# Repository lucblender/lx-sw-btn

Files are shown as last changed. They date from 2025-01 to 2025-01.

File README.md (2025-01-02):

# lx-sw-btn

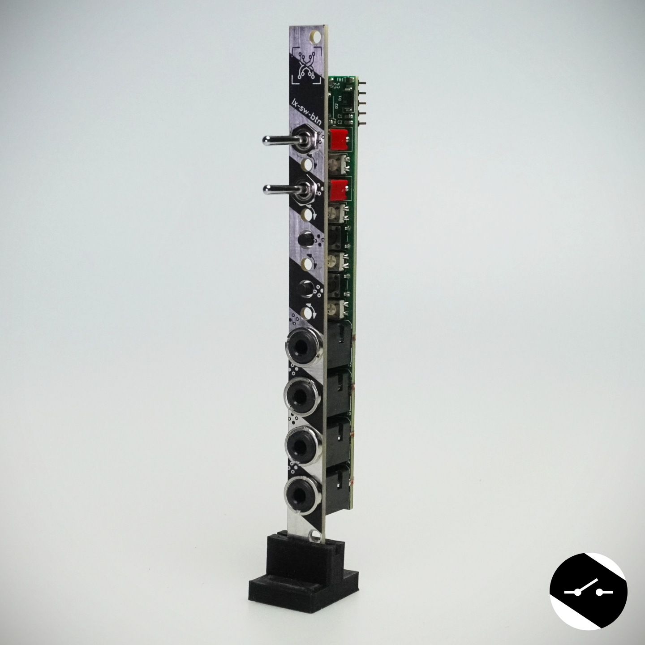
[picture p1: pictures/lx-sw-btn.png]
lx-sw-btn


This repository contains the KiCad project for the "lx-sw-btn": a 2HP eurorack module with 4 customizable switches enabled CV outputs!

With two buttons and two switches, the lx-sw-btn enables four CV "on-off" outputs. By default, the output is set to 0-5V, but each output can be fine-tuned through front-panel adjustment holes ranging from -10V to +10V. This will allow you to use the switches not only as triggers but also for precise CV control.

The module is extremely compact with only a single PCB featuring SMD components on both sides, ensuring no wasted space!

I used [PCBWay](pcbway.com) services were used for the PCB manufacturing, both pcb and front panel.

## Content

Under the [hardware](/hardware/) folder, you will find the KiCad project with the following files:

- [Project](/hardware/2hp-simple-switch-button/2hp-simple-switch-button.kicad_pro)
- [Schematic](/hardware/2hp-simple-switch-button/2hp-simple-switch-button.kicad_sch)
- [Main PCB](/hardware/2hp-simple-switch-button/2hp-simple-switch-button.kicad_pcb)
- [Front panel PCB](/hardware/2hp-simple-switch-button/2hp-simple-switch-button-front-panel.kicad_pcb)

## Circuit

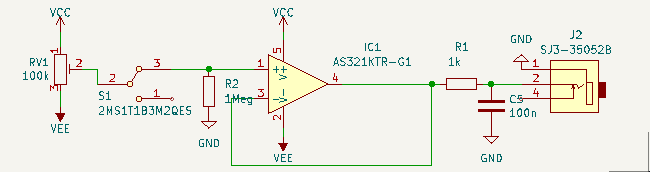
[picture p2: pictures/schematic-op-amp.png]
schematic-exerp


The circuit consist of 4 times the circuit below: an opamp as follower with a voltage devider between VCC and VEE as input through a potentiometer. The output is set to 1k impedance with a RC filter useful for debouncing the switches and buttons.

The module also have power supply invert polarity protection and input filtering.

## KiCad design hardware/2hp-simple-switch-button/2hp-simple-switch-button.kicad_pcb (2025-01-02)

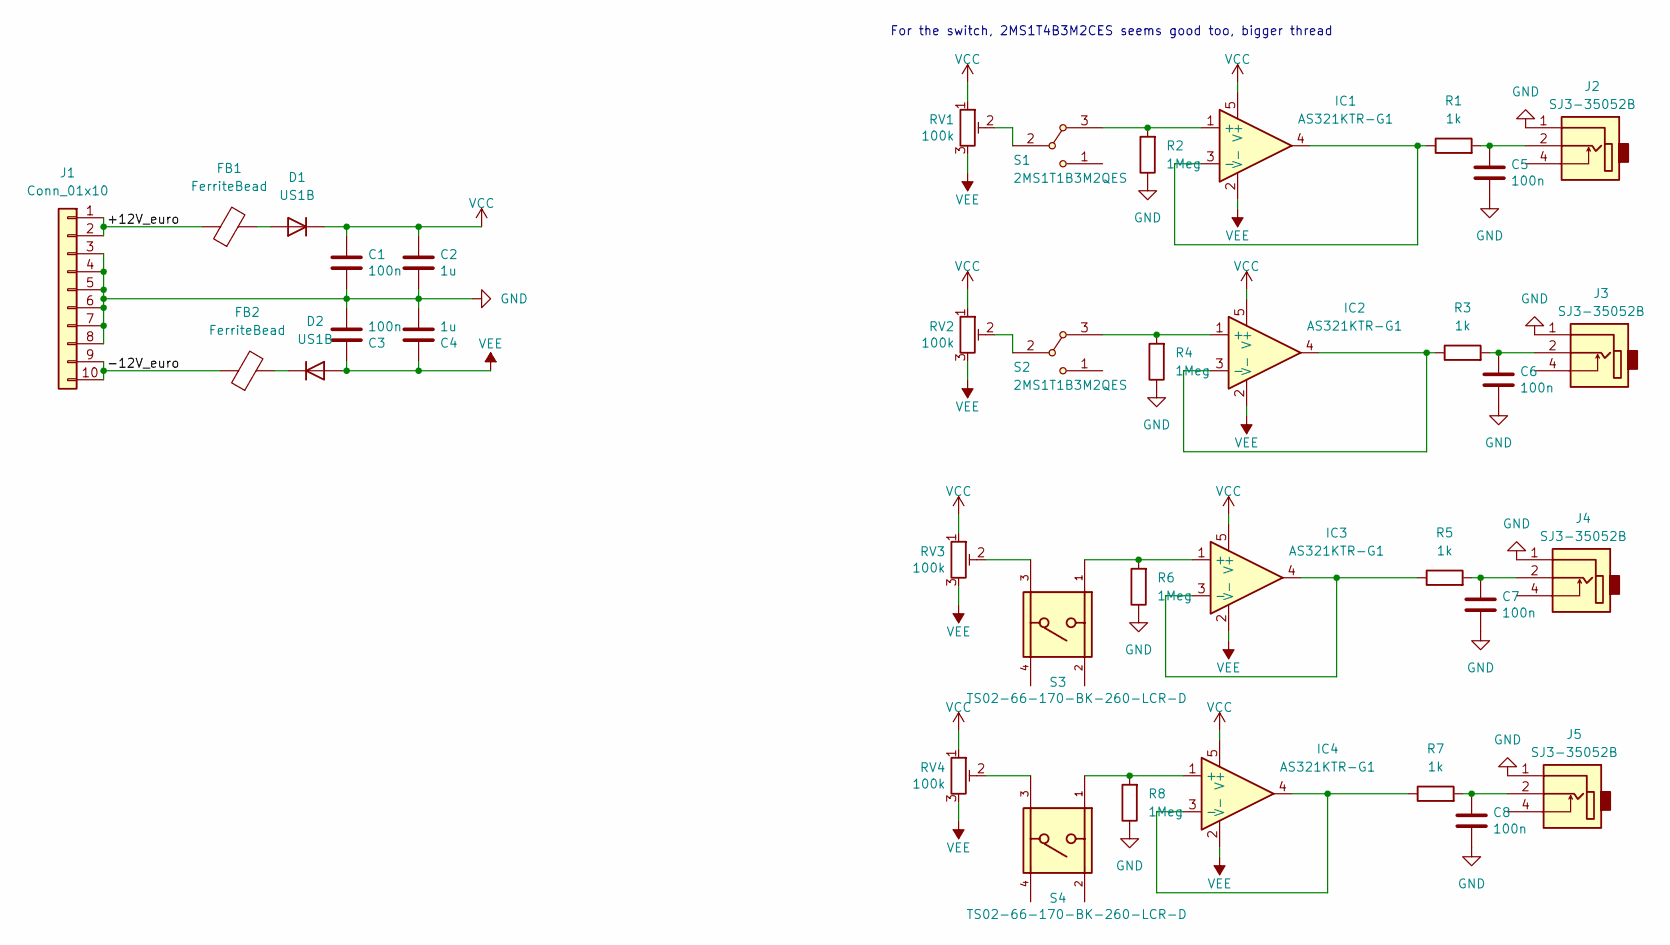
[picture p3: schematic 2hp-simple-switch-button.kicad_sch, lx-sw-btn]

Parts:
C1, C3, C5, C6, C7, C8: 100n; C_0603_1608Metric; Mouser Part Number 581-06031C104MAT2A; LCSC C14663
C2, C4: 1u; C_0603_1608Metric; Mouser Part Number 187-CL10B105KO8NNWC; LCSC C14663
D1, D2: US1B; D_SMA; Mouser Part Number 637-US1B
FB1, FB2: FerriteBead; L_0805_2012Metric; Mouser Part Number 710-742792031
IC1, IC2, IC3, IC4: AS321KTR-G1; SOT95P282X145-5N; Mouser Part Number 621-AS321KTR-G1
J1: Conn_01x10; PinHeader_2x05_P2.54mm_Vertical_SMD; Mouser Part Number 200-TSM10501LDVPTR
J2, J3, J4, J5: SJ3-35052B; SJ335052B; Mouser Part Number 179-SJ3-35052B
R1, R3, R5, R7: 1k; R_0805_2012Metric; Mouser Part Number RT0805FRE071KL
R2, R4, R6, R8: 1Meg; R_0805_2012Metric; Mouser Part Number 72-TS53YL-100K
RV1, RV2, RV3, RV4: 100k; Potentiometer_Vishay_TS53YL_Vertical; Mouser Part Number 72-TS53YL-100K
S1, S2: 2MS1T1B3M2QES; Mouser Part Number 118-2MS1T1B3M2QES or 118-2MS1T4B3M2CES
S3, S4: TS02-66-170-BK-260-LCR-D; SW_TS02-66-170-BK-260-LCR-D; PARTREV 1.0; Mouser Part Number 179-TS0266170BK260LC

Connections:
/+12V_euro: FB1.1, J1.1, J1.2
/-12V_euro: FB2.1, J1.9, J1.10
GND: C1.2, C2.2, C3.2, C4.2, C5.2, C6.2, C7.2, C8.2, J1.3, J1.4, J1.5, J1.6, J1.7, J1.8, J2.1, J3.1, J4.1, J5.1, R2.1, R4.1, R6.1, R8.1
unnamed: C5.1, J2.2, R1.2
unnamed: C6.1, J3.2, R3.2
unnamed: C7.1, J4.2, R5.2
unnamed: C8.1, J5.2, R7.2
unnamed: D1.2 (A), FB1.2
unnamed: D2.1 (K), FB2.2
unnamed: IC1.1 (+), R2.2, S1.3
unnamed: IC1.3 (-), IC1.4, R1.1
unnamed: IC2.1 (+), R4.2, S2.3
unnamed: IC2.3 (-), IC2.4, R3.1
unnamed: IC3.1 (+), R6.2, S3.1
unnamed: IC3.3 (-), IC3.4, R5.1
unnamed: IC4.1 (+), R8.2, S4.1
unnamed: IC4.3 (-), IC4.4, R7.1
unnamed: RV1.2, S1.2
unnamed: RV2.2, S2.2
unnamed: RV3.2, S3.3
unnamed: RV4.2, S4.3
VCC: C1.1, C2.1, D1.1 (K), IC1.5 (V+), IC2.5 (V+), IC3.5 (V+), IC4.5 (V+), RV1.1, RV2.1, RV3.1, RV4.1
VEE: C3.1, C4.1, D2.2 (A), IC1.2 (V-), IC2.2 (V-), IC3.2 (V-), IC4.2 (V-), RV1.3, RV2.3, RV3.3, RV4.3

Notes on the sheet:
For the switch, 2MS1T4B3M2CES seems good too, bigger thread

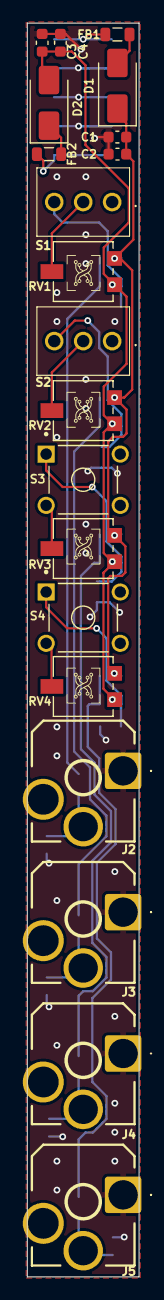
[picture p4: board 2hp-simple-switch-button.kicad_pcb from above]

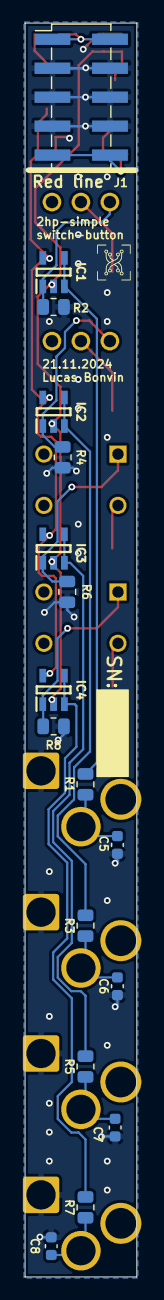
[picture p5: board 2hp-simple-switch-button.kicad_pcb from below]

Board: 2 copper layers, 9.8 x 110.0 mm, 37 parts (17 on the bottom side), 23 nets.
